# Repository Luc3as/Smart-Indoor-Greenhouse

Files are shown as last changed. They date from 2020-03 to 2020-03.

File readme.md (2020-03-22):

## Idea behind this project
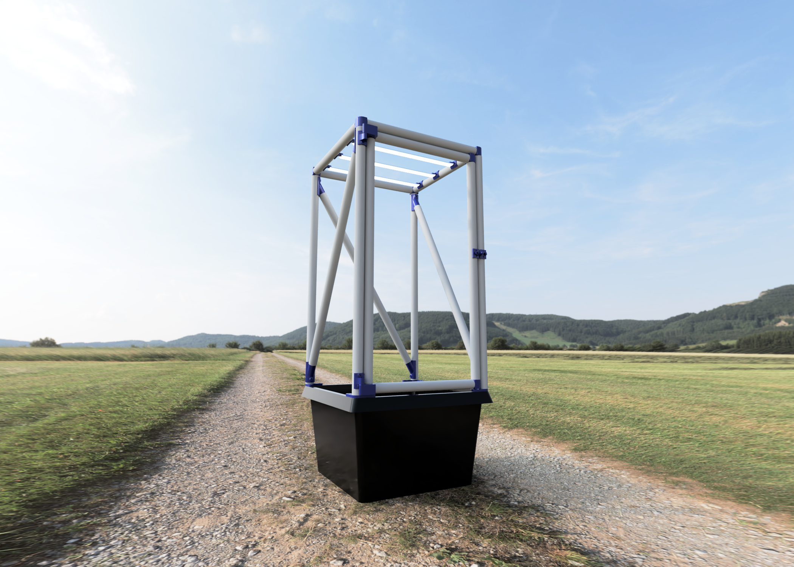
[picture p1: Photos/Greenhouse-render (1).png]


Simple but functional indoor greenhouse, with intergalactic space design and smart capabilities, powered by ESPHome and HomeAssistant.

We had one big pot with herbs in our kitchen, but in winter, there is not enough light to grow them at reasonable rate. So I came with idea to build some cover around it, and of course to make it smart, because who would remember to water it anyaway right ? 

## Design and build
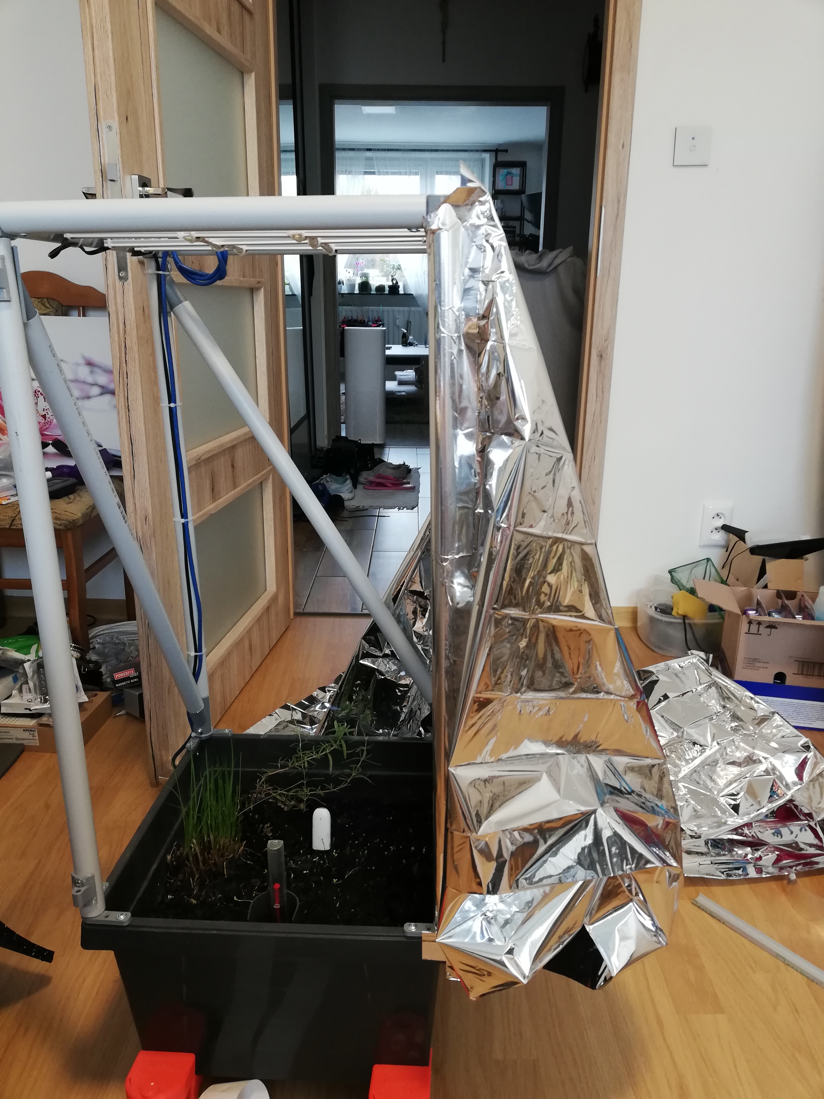
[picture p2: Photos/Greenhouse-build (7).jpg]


I sketched whole thing in Fusion360 and started to print the parts. 

The frame is made from 3D printed cornes, and tubes for electrical installations with inner diameter of 22mm , you can get them in 3 meter lengths pretty cheap. 

Whole frame is screwed together with corner parts, and as wall material I used 2 layers of isotermic foil which you can find in car firs-aid kit or in pharmacy for like 2 €. Foil is attached with  aluminium tape used for insulation of water pipes. 

You could probably use any dimensions of pot, and adjust it by cutting different lengths of pipes. I luckily chosen just right dimension so on the top there fits just right some lid from IKEA, so I dind't have to think about what material I could use.

Pot itself is self-watering, it has reservoir at the bottom and it is draining the water through some wicks under the soil. For now , I don't need to solve watering by some pump, but this could be fairly easy to implement by another transistor connected to ESP32, controlling the water-pump. We will see how it will go in the hotter months. 

## Electronics
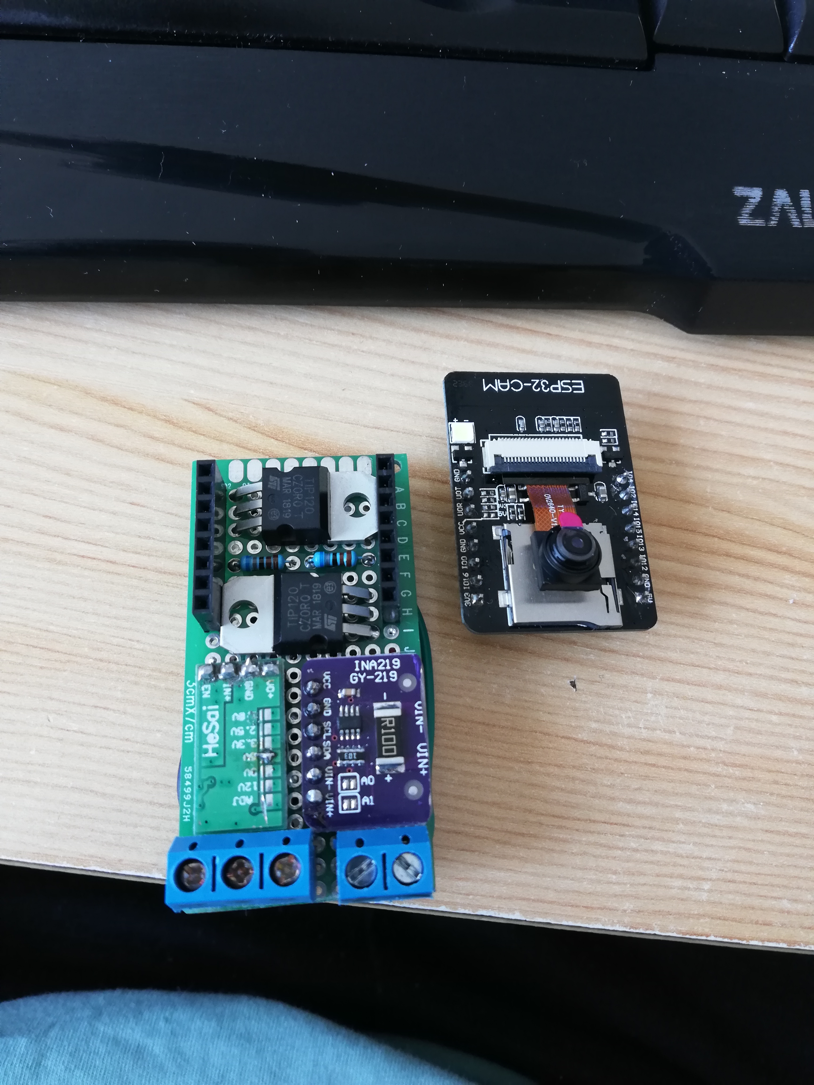
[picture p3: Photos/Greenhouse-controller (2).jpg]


At the top there are 3 LED light bars, as you can see I just improvised and attached another red-blue grow lights, as well as IR and UV leds, by just zipties. I was searching for decent grow lights but It costs quite enough for this proof of concept, but I noticed there are also IR and UV leds in some ratio. So I ordered spare IR blaster for CCTV camera, and shortest possible strip of UV leds. They are controlled by NPN transistor, driven from ESP32-CAM board. The same applies to the fan at the TOP. 

I didn't sketched PCB for this project, all is installed on 30 x 50 protoboard. 
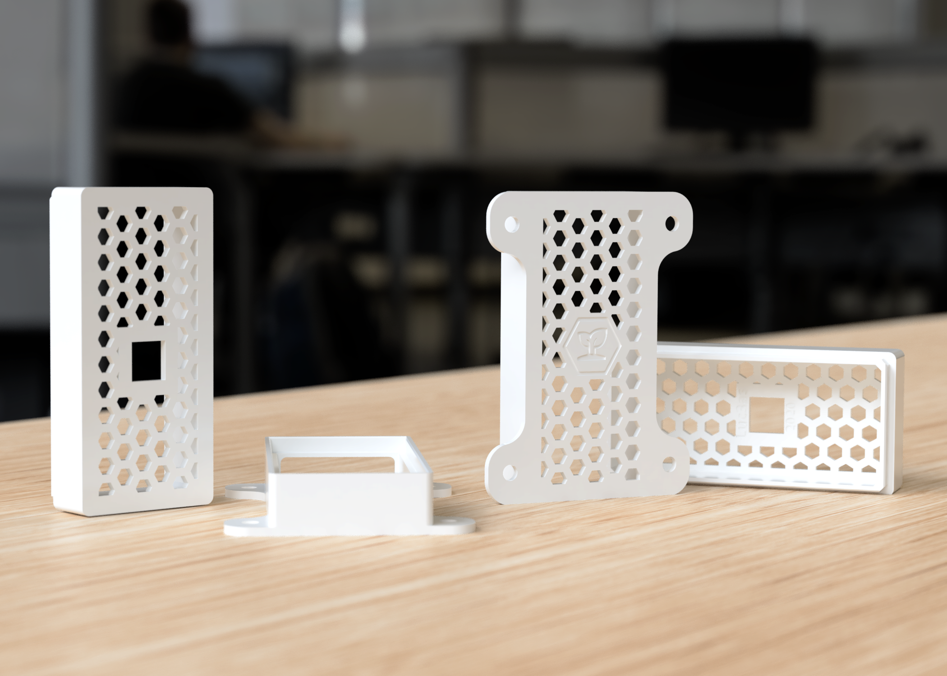
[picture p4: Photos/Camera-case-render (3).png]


### Sensors
There is Xiaomi MiFlora sensor in the soil, I wanted to ESP32 act as Bluetooth gateway, because with aluminium foil all around you basically create faradays cage, so there is quite problem to get the signal out of it, But soon I realised that I wanted too much from ESP32 board, to handle the camera stream, control 2 channels of PWM for LEDS and fan, and to track BLE devices. I will solve this by reading the datas from MiFlora by another device. 

I wanted to have camera at the top, so I could take photos and make some time-lapse of growing. 

Power consumption of whole system is measured by INA219 board, it communicates through I2C, and it's simple to use. I calculate the price for our country, you'll have to edit this in sketch. 

## Data view
I also designed lovelace card for showing all informations about greenhouse. 

You should have card-mod addon for lovelace installed, as I am using it to change css style of card. There is folder Lovelace-card-resources with files you should copy to your www folder, as I am using it in card.

Lovelace config is in lovelace-card.yaml file.

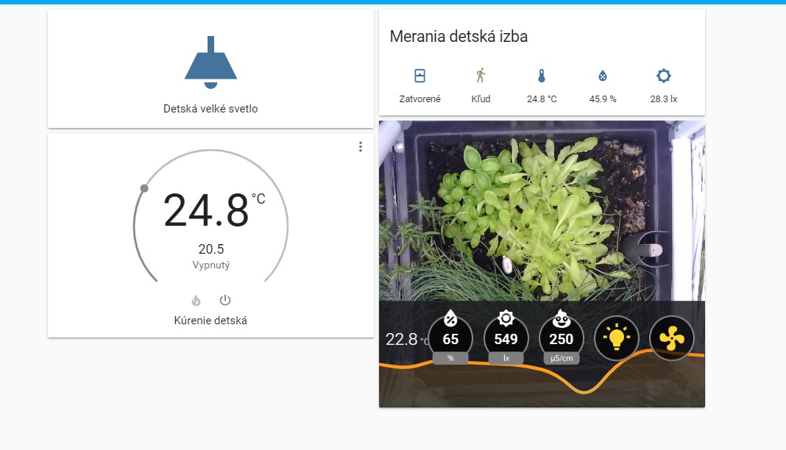
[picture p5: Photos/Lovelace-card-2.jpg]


## TimeLapse videos
I am making snapshots through HomeAssistant automation saving all files in local www folder, and then massage  these photos through NodeRed, which outputs gif files, and I am showing these gif files as local_file camera. All neccessary config files are included. 

All files can be find [on my thingiverse.com/Luc3as](https://www.thingiverse.com/thing:4233190)

### If You liked my work, You can buy me a coffee :)

<a class="" target="_blank" href="https://www.buymeacoffee.com/luc3as">Buy Me A Coffee</a>

### Or send some crypto

<a class="" target="_blank" href="https://lukasporubcan.sk/donate">Donate Bitcoin</a>

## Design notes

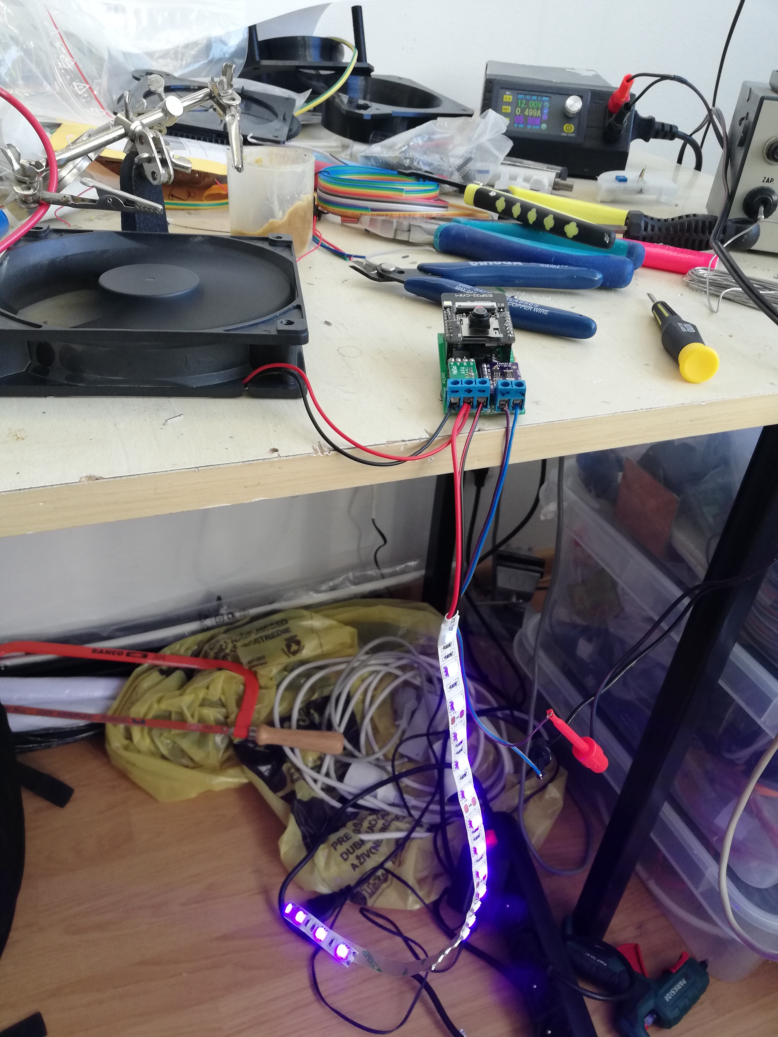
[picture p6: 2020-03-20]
Photos/Greenhouse-controller (1).jpg

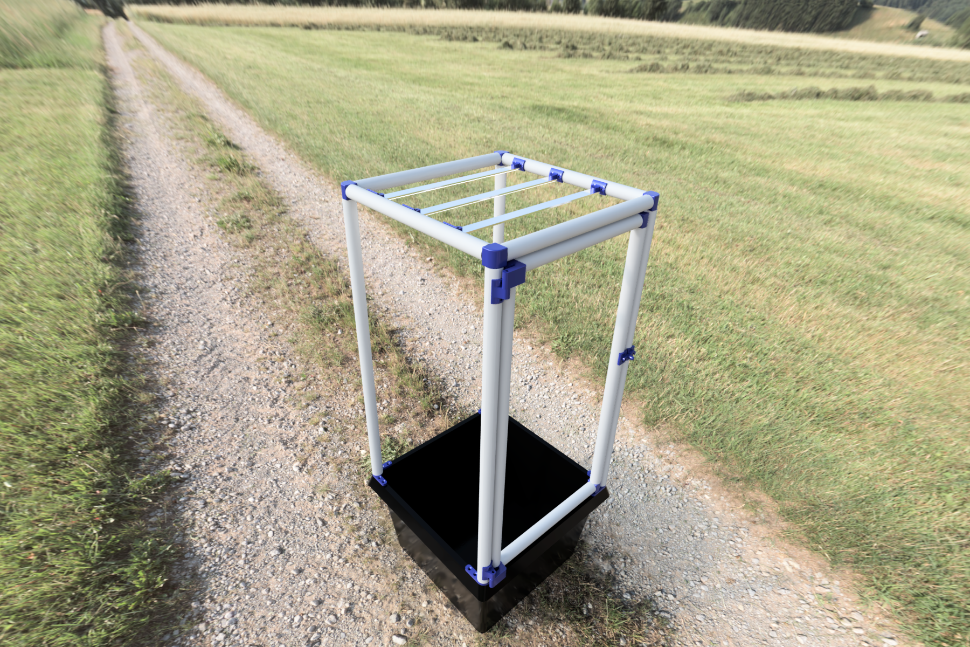
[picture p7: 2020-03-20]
Photos/Greenhouse-render (3).png

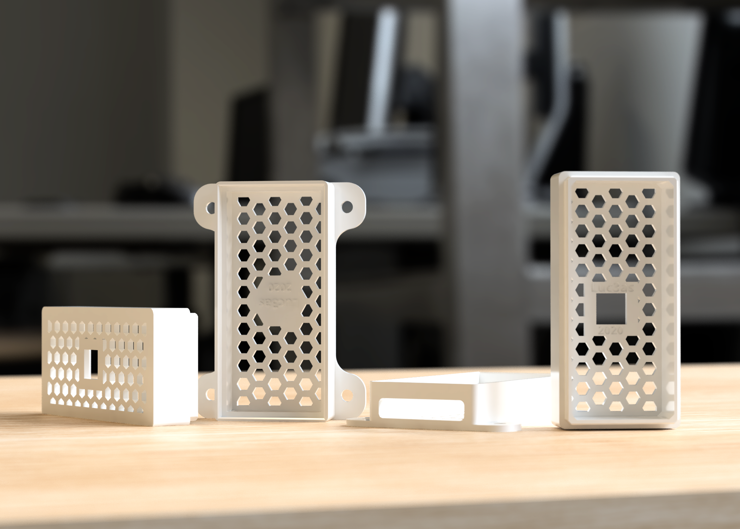
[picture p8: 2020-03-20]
Photos/Camera-case-render (4).png

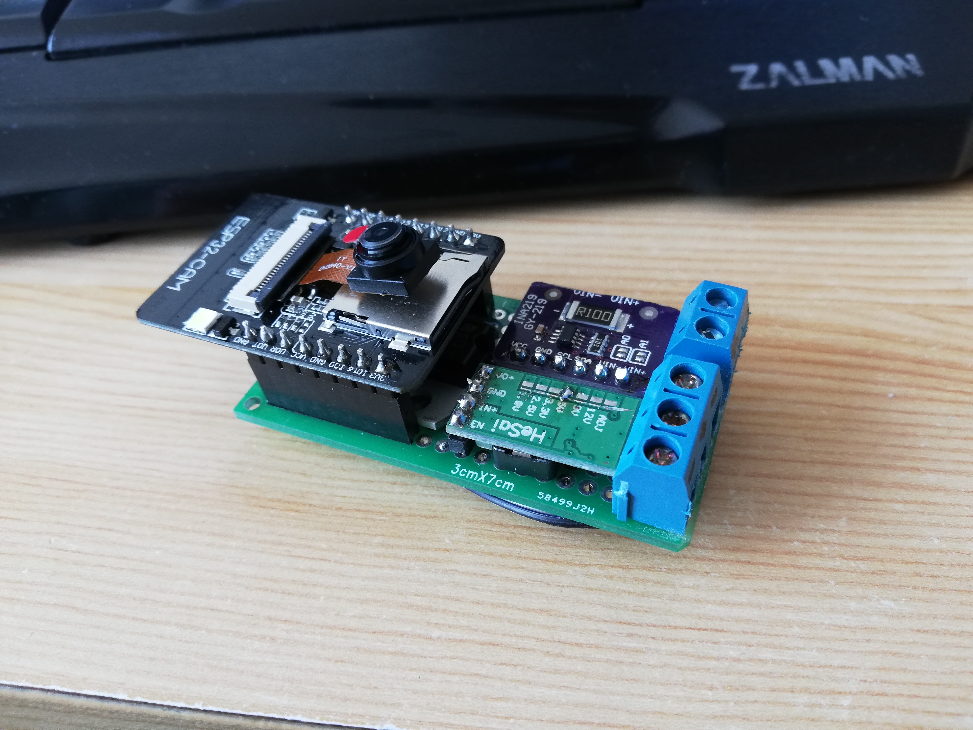
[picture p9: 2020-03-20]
Photos/Greenhouse-controller (3).jpg

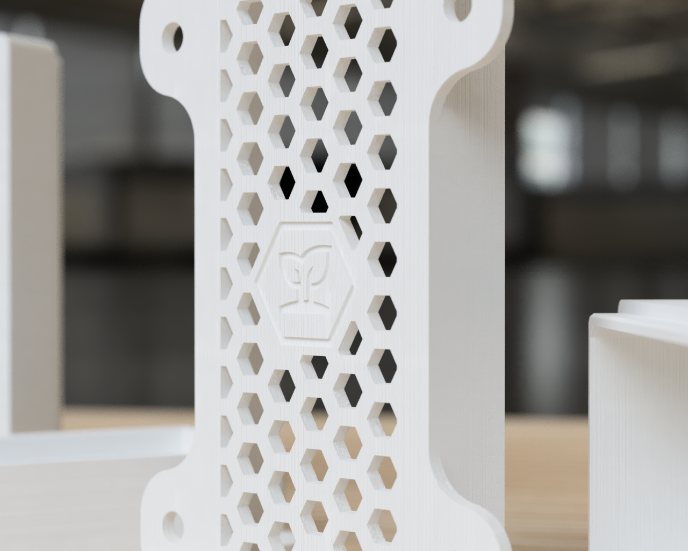
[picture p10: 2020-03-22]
Photos/Camera-case-render (5).png

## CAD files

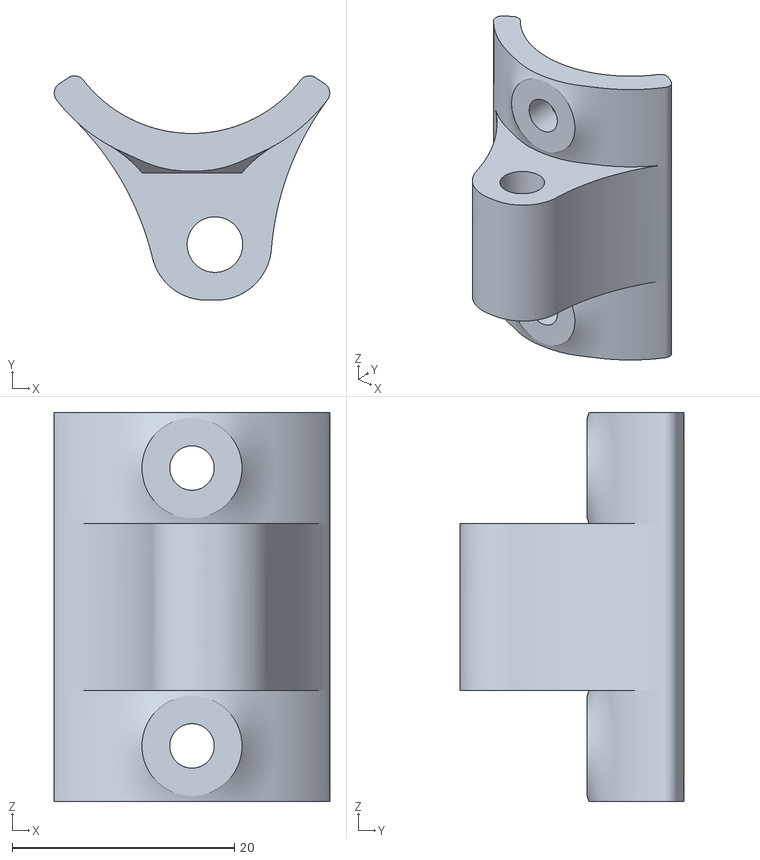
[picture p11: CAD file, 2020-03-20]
STLs/Hinge holder 2x.stl
24.8 x 20.2 x 35.0

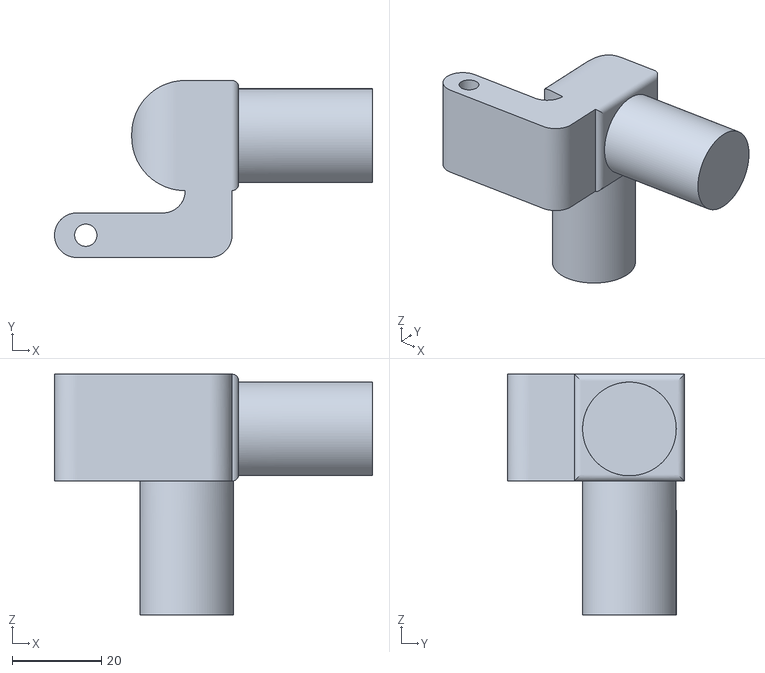
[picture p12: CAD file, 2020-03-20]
STLs/Door corner with hinge b.stl
71.3 x 39.7 x 54.0

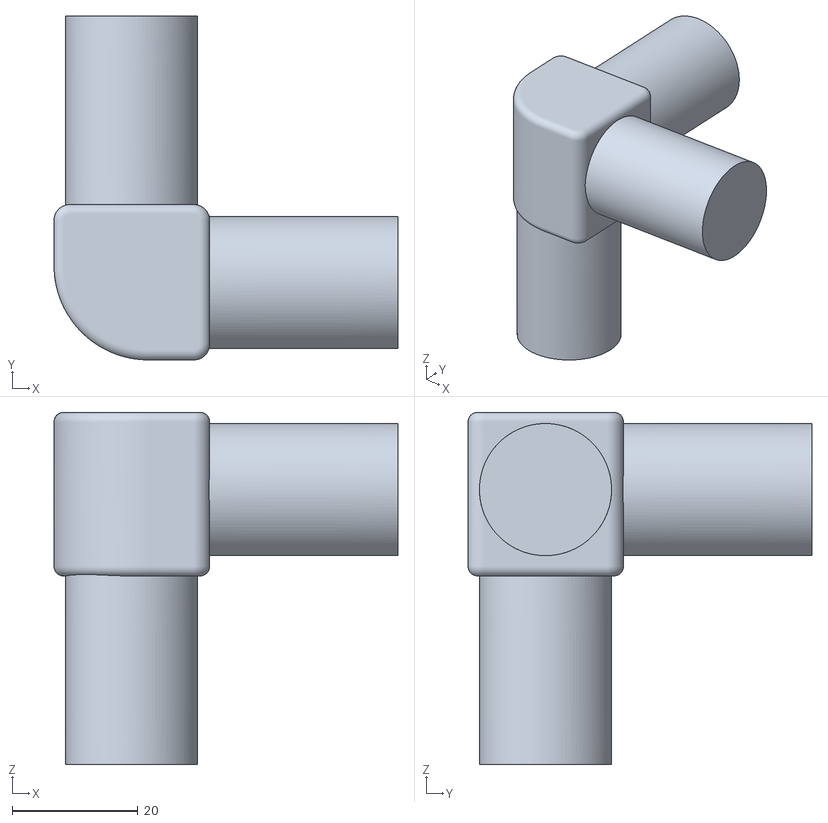
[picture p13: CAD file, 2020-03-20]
STLs/Top ring corner 4x.stl
54.7 x 54.7 x 56.0

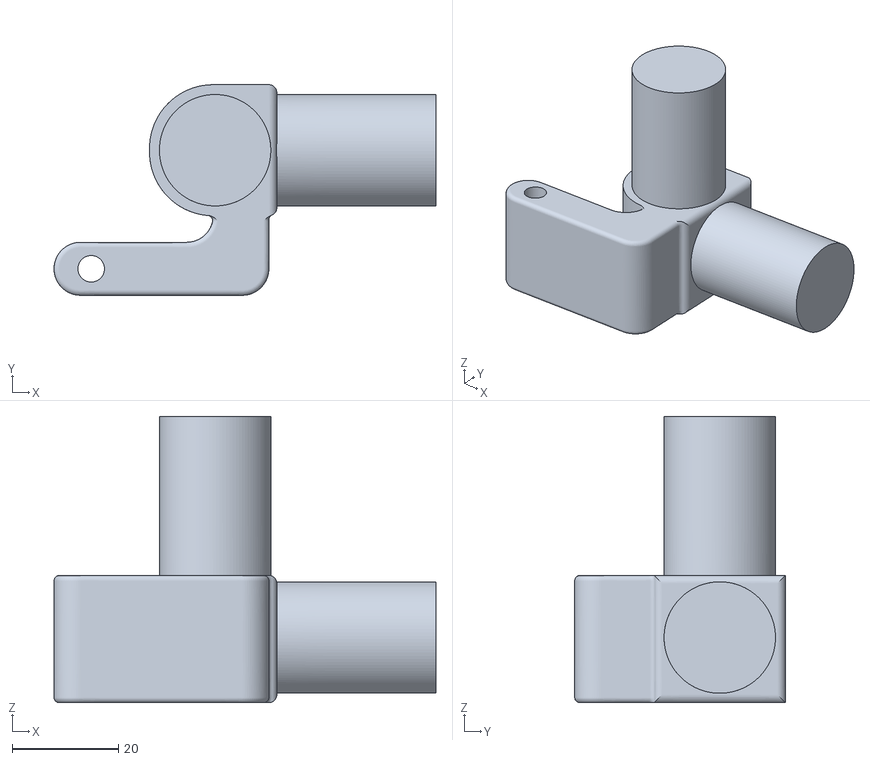
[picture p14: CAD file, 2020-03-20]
STLs/Door corner with hinge a.stl
72.0 x 39.7 x 54.0

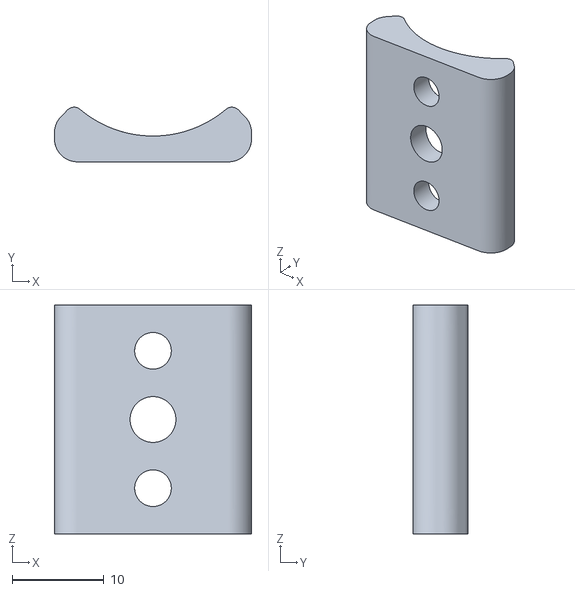
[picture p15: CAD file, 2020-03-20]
STLs/Door knob 2x.stl
21.5 x 5.97 x 25.0

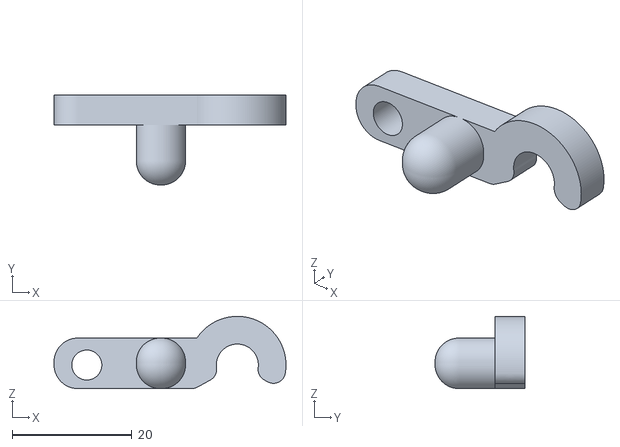
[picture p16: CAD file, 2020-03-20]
STLs/Door lock.stl
38.7 x 15.0 x 12.0

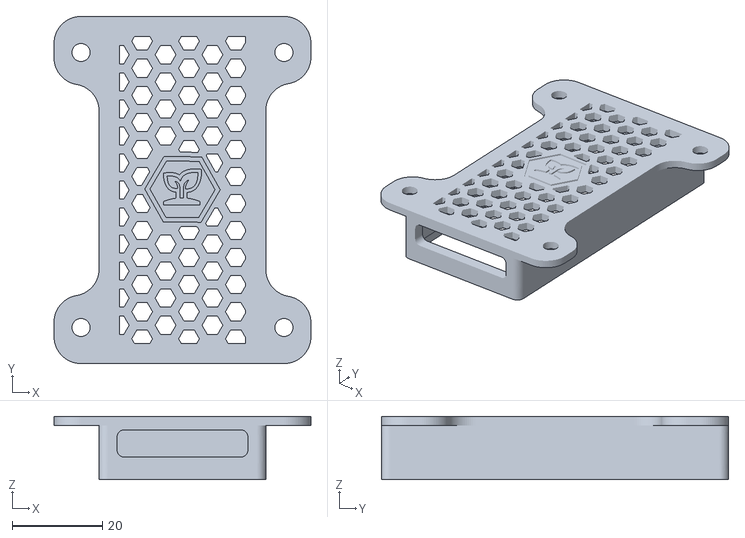
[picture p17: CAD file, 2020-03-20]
STLs/Camera case bottom.stl
57.0 x 77.0 x 14.0

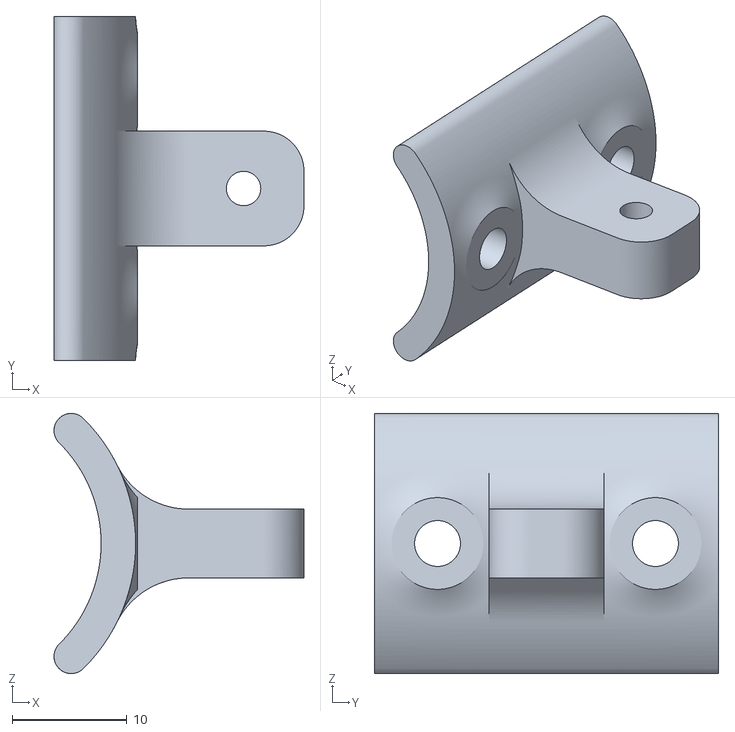
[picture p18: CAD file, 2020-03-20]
STLs/LED mount 8x.stl
21.8 x 30.0 x 22.7

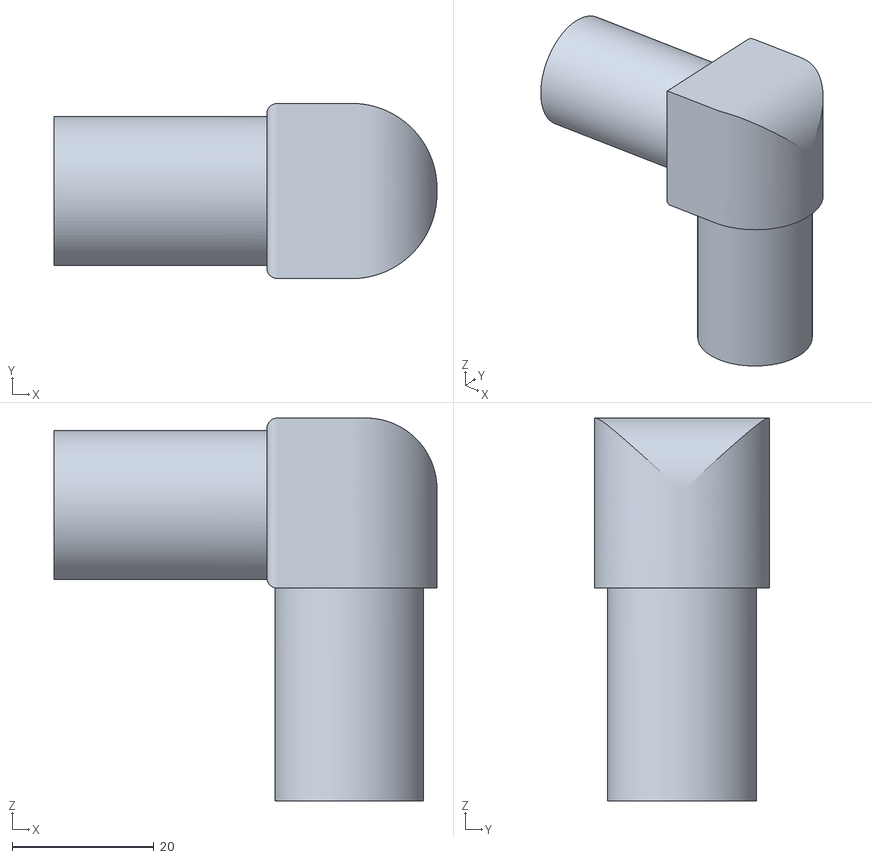
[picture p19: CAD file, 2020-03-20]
STLs/Door corner 2x.stl
54.0 x 24.7 x 54.0

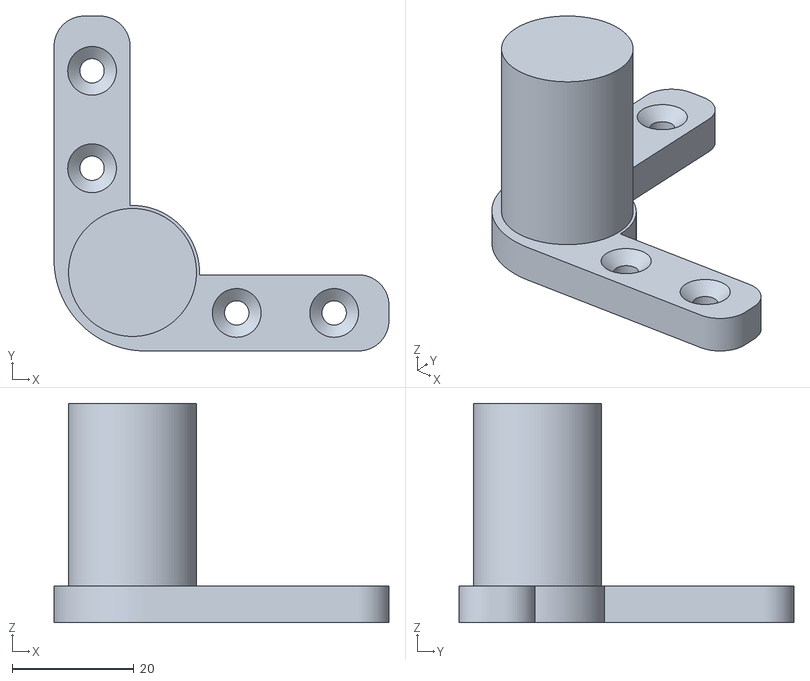
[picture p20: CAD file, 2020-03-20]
STLs/Bottom corner 4x.stl
55.0 x 55.0 x 36.0

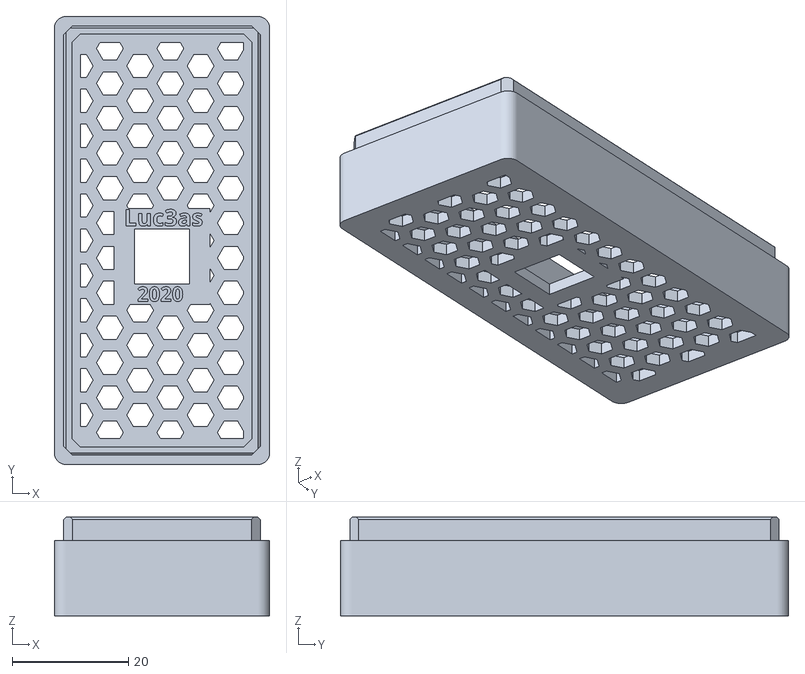
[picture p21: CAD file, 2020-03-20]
STLs/Camera case top.stl
37.0 x 77.0 x 17.0

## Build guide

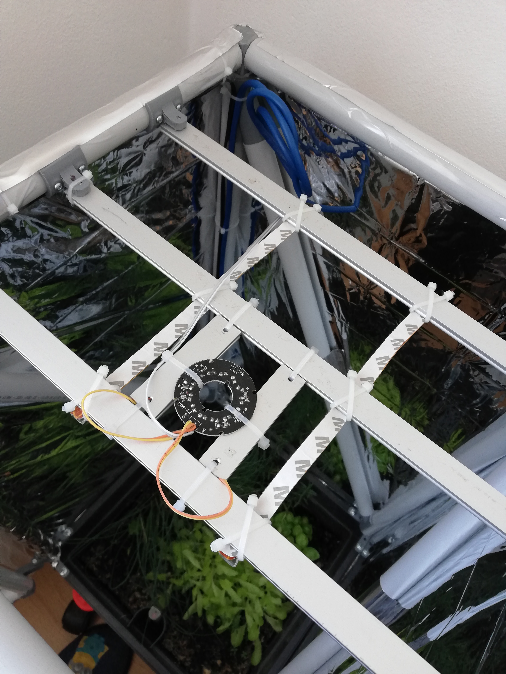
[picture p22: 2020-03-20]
Photos/Greenhouse-build (1).jpg

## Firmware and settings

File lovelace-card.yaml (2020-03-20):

elements:
  - camera_image: camera.sklennik
    camera_view: live
    entity: camera.sklennik
    style:
      left: 45%
      top: 55%
      width: 130%
    type: image
  - image: /local/sklennik-card/background2.png
    style:
      left: 50%
      top: 82%
      width: 101%
    tap_action: none
    type: image
  - color_thresholds:
      - color: '#4dd2ff'
        value: 18
      - color: '#ffa31a'
        value: 22
      - color: '#ff1a1a'
        value: 26
    entities:
      - sensor.bylinky_teplota_3
    icon: 'mdi:home-thermometer-outline'
    show:
      icon: false
      legend: false
      name: false
    style: |
      :host {
        left: 50%;
        top: 85.5%;
        width: 100% !important;
        overflow: hidden;
        height: 29%;
        background: none  !important;
        box-shadow: none !important;
        //border: 1px solid red !important;
        
      }
      .header {
        font-size: 1vw;
        position: absolute !important;
        width: 25% !important;
        padding: 0 !important;
        right: 10% !important;
        top: 15% !important;
        color: white;

      }
      ha-card {
        background: none  !important;
        padding: 0 !important;
        
      }
      .icon > ha-icon {
        width:1.8vw !important;
        height:1.8vw !important;
        
      }
      .state__time{
        font-size:0.9vw !important;
        margin-top: 0.2vw;
        font-weight: 300 !important;
        opacity: 0.4 !important;
      }
      .states {
        font-size: 0.5vw !important;
        padding: 1vw 0vw 0vw 0vw  !important;
        margin: auto !important;
        position: absolute !important;
        padding: 0 !important;
        left: 2% !important;
        top: 6% !important;
        color: white;
      }
    type: 'custom:mini-graph-card'
  - image: /local/sklennik-card/circle.png
    style:
      left: 22%
      top: 76%
      width: 14%
    type: image
  - image: /local/sklennik-card/water-percent.png
    style:
      left: 22%
      top: 69%
      width: 8%
    type: image
  - entity: sensor.bylinky_vlhost_cislo
    style:
      font-size: 1vw
      font-weight: 500
      left: 22%
      top: 76.5%
      color: white
    type: state-label
  - image: /local/sklennik-card/percent.png
    style:
      left: 22%
      top: 83%
      width: 11%
    type: image
  - image: /local/sklennik-card/circle.png
    style:
      left: 39%
      top: 76%
      width: 14%
    type: image
  - image: /local/sklennik-card/brightness-7.png
    style:
      left: 39%
      top: 69%
      width: 6%
    type: image
  - entity: sensor.bylinky_svetlo_cislo
    style:
      font-size: 1vw
      font-weight: 500
      left: 39%
      top: 76.5%
      color: white
    type: state-label
  - image: /local/sklennik-card/lx.png
    style:
      left: 39%
      top: 83%
      width: 11%
    type: image
  - image: /local/sklennik-card/circle.png
    style:
      left: 56%
      top: 76%
      width: 14%
    type: image
  - image: /local/sklennik-card/emoticon-poop.png
    style:
      left: 56%
      top: 69%
      width: 7%
    type: image
  - entity: sensor.bylinky_hnojivo_cislo
    style:
      font-size: 1vw
      font-weight: 500
      left: 56%
      top: 76.5%
      color: white
    type: state-label
  - image: /local/sklennik-card/uscm.png
    style:
      left: 56%
      top: 83%
      width: 11%
    type: image
  - image: /local/sklennik-card/circle.png
    style:
      left: 73%
      top: 76%
      width: 14%
    type: image
  - entity: light.sklennik_svetla
    state_image:
      'off': /local/sklennik-card/lightbulb-off.png
      'on': /local/sklennik-card/lightbulb-on.png
    style:
      left: 73%
      top: 75.5%
      width: 9%
    tap_action:
      action: toggle
    type: image
  - image: /local/sklennik-card/circle.png
    style:
      left: 90%
      top: 76%
      width: 14%
    type: image
  - entity: fan.sklennik_vetranie
    state_image:
      'off': /local/sklennik-card/fan-off.png
      'on': /local/sklennik-card/fan-on.png
    style:
      left: 90%
      top: 76%
      width: 9%
    tap_action:
      action: toggle
    type: image
image: /local/sklennik-card/transparent.png
type: picture-elements

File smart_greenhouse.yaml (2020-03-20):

substitutions:
  devicename: "smart_greenhouse"
  upper_devicename: "Smart Greenhouse"

esphome:
  name: $devicename
  platform: ESP32
  board: esp-wrover-kit

wifi:
  ssid: "WiFi"
  password: !secret LukiaMajka_WIFI_PASS
  
# Enable logging
logger:
#  level: WARN

# Enable Home Assistant API
api:
  password: !secret esphome_api_pass

ota:
  password: !secret esphome_ota_pass

time:
  - platform: homeassistant
  
#esp32_ble_tracker:    
#  scan_parameters:
#    interval: 1520ms
#    window: 320ms
#    active: false

text_sensor:
  - platform: template
    name: ${upper_devicename} uptime
    lambda: |-
      uint32_t dur = id(uptime_s).state;
      int dys = 0;
      int hrs = 0;
      int mnts = 0;
      if (dur > 86399) {
        dys = trunc(dur / 86400);
        dur = dur - (dys * 86400);
      }
      if (dur > 3599) {
        hrs = trunc(dur / 3600);
        dur = dur - (hrs * 3600);
      }
      if (dur > 59) {
        mnts = trunc(dur / 60);
        dur = dur - (mnts * 60);
      }
      char buffer[17];
      sprintf(buffer, "%ud %02uh %02um %02us", dys, hrs, mnts, dur);
      return {buffer};
    icon: mdi:clock-start
    update_interval: 30s
  
sensor:
  - platform: uptime
    id: uptime_s
    update_interval: 30s
  - platform: wifi_signal
    name: ${upper_devicename} WiFi Signal
    update_interval: 60s  

  - platform: ina219
    address: 0x40
    i2c_id: bus_a
    current:
      name: ${upper_devicename} current
      filters:
        - multiply: 100
    power:
      name: ${upper_devicename} power
      filters:
        - multiply: 100
      id: ${devicename}_spotreba
    bus_voltage:
      name: ${upper_devicename} voltage
    shunt_voltage:
      name: ${upper_devicename} voltage at resistor
    max_voltage: 13V
    max_current: 2.2A
    update_interval: 10s    

  - platform: total_daily_energy
    name: ${upper_devicename} today's power consumption 
    power_id: ${devicename}_spotreba
    id: ${devicename}_dnesna_spotreba

  - platform: template
    name: ${upper_devicename} price for today
    unit_of_measurement: "€"
    lambda: |-
      return id(${devicename}_dnesna_spotreba).state * 0.001 * 0.16 ;
    update_interval: 60s
    icon: mdi:currency-eur
  
#  - platform: xiaomi_hhccjcy01
#    mac_address: 'C4:7C:8D:66:DA:81'
#    temperature:
#      name: "Bylinky teplota"
#    moisture:
#      name: "Bylinky vlhkosť"
#    illuminance:
#      name: "Bylinky svetlo"
#    conductivity:
#      name: "Bylinky hnojivo"
#    battery_level:
#      name: "Bylinky batéria"
    
switch:
  - platform: restart
    name: ${upper_devicename} restart

esp32_camera:
  external_clock:
    pin: GPIO0
    frequency: 20MHz
  i2c_pins:
    sda: GPIO26
    scl: GPIO27
  data_pins: [GPIO5, GPIO18, GPIO19, GPIO21, GPIO36, GPIO39, GPIO34, GPIO35]
  vsync_pin: GPIO25
  href_pin: GPIO23
  pixel_clock_pin: GPIO22
  power_down_pin: GPIO32
  resolution: XGA
  max_framerate: 1 fps
  jpeg_quality: 10
  name: ${upper_devicename}   
  
i2c:
  sda: GPIO2
  scl: GPIO13
  scan: True
  id: bus_a
  
output:
  - platform: ledc
    pin: GPIO14
    id: led_output
    channel: 2
  - platform: ledc
    pin: GPIO15
    id: fan_output  
    channel: 3
    
light:
  - platform: monochromatic
    output: led_output
    name: ${upper_devicename} lights 
    
fan:
  - platform: speed
    output: fan_output
    name: ${upper_devicename} ventilation  
    speed:
      low: 0.20
      medium: 0.40
      high: 0.60
